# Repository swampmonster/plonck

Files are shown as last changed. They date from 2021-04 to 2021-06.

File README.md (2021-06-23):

# plonck

An attempt at making a planck-compatible pcb with bluetooth  
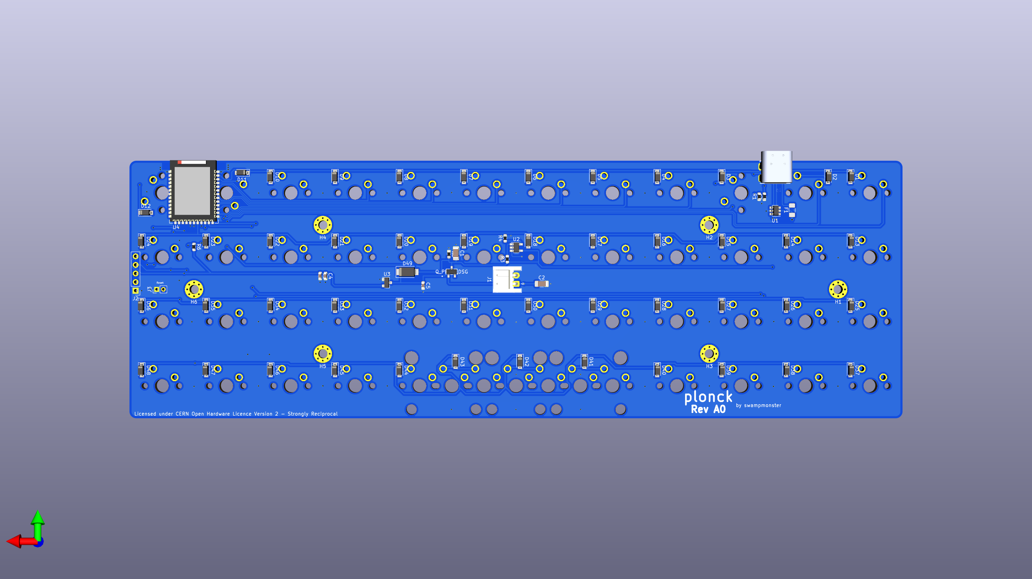
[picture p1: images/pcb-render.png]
PCB Render


## Current status:
### Rev A0 (NOT RECOMMENDED FOR PRODUCTION, READ STATUS)
I've received and built this version and it works fine but i made the mistake of wiring up the GND and VBUS pins on the ESD chip incorrectly.  
Thankfully those are the middle pins and simply desoldering and turning the chip around solves the problem.  
Update: Finally had time to test the load sharing circuitry and i had the pinout of the mosfet setup incorrectly which requires bodge wires to fix.  
If you are looking to get boards made from this revision you need to be aware of this but my recommendation would be to wait for the next one.

## Rev B0
This should address all the issues in A0 while also adding some features that were not previously present such as:  
- Leds for charge and bootloader status.
- Voltage divider for charge monitoring.
- SMD USB port so it can be mounted by JLC.

Boards have been ordered but not yet received so production is still not recommended.

## License
The project is licensed under [CERN-OHL-S](LICENSE) (see [LICENSE](LICENSE) file) with the exceptions of:
- The [MX_Alps_Hybrid](MX_Alps_Hybrid) directory which is licensed under the [MIT License](https://opensource.org/licenses/MIT) and is made by [ai03](https://github.com/ai03-2725/MX_Alps_Hybrid).
- The [USB4085-GF-A_REVA](USB4085-GF-A_REVA) directory which is licensed under the [Creative Commons Attribution-ShareAlike 4.0 International License](https://creativecommons.org/licenses/by-sa/4.0/) and comes from [SnapEDA](https://www.snapeda.com/parts/USB4085-GF-A/Global%20Connector%20Technology/view-part/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).
- The [PTS525SM15SMTR2LFS](PTS525SM15SMTR2LFS) directory which is licensed under the [Creative Commons Attribution-ShareAlike 4.0 International License](https://creativecommons.org/licenses/by-sa/4.0/) and comes from [SnapEDA](https://www.snapeda.com/parts/PTS525SM15SMTR2%20LFS/C&K/view-part/?ref=search&t=PTS525).
- The [SM02B-SRSS-TB_LF__SN_](SM02B-SRSS-TB_LF__SN_) directory which is licensed under the [Creative Commons Attribution-ShareAlike 4.0 International License](https://creativecommons.org/licenses/by-sa/4.0/) and comes from [SnapEDA](https://www.snapeda.com/parts/SM02B-SRSS-TB%28LF%29%28SN%29/JST%20Sales/view-part/447499).
- The [ul_SI2301CDST1GE3](ul_SI2301CDST1GE3) directory which is licensed under the terms provided in the Terms and Conditions on [Ultra Librarian](https://www.ultralibrarian.com/)

## Thanks
Huge shoutout to [4pplet](https://github.com/4pplet) for tons of advice and help.

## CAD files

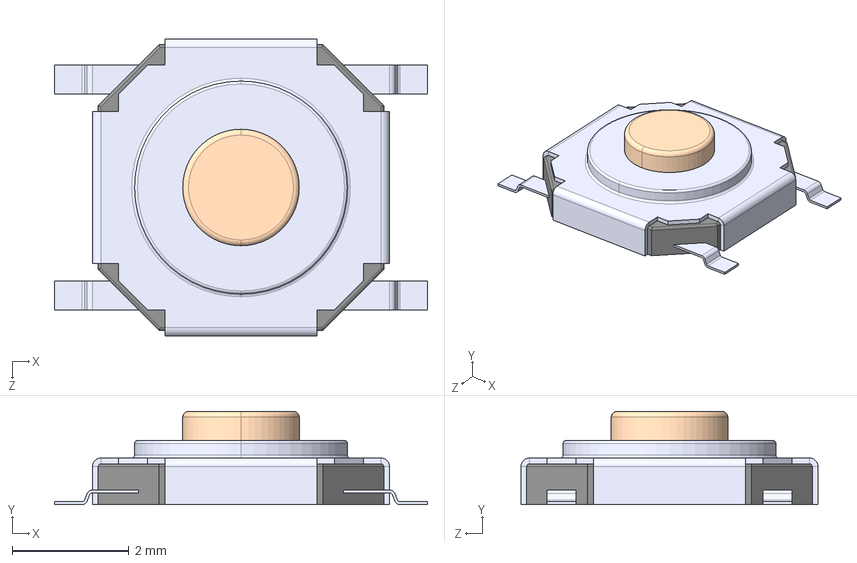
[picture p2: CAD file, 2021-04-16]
PTS525SM15SMTR2LFS/PTS525SM15SMTR2LFS.step
6.40 x 1.60 x 5.10 mm

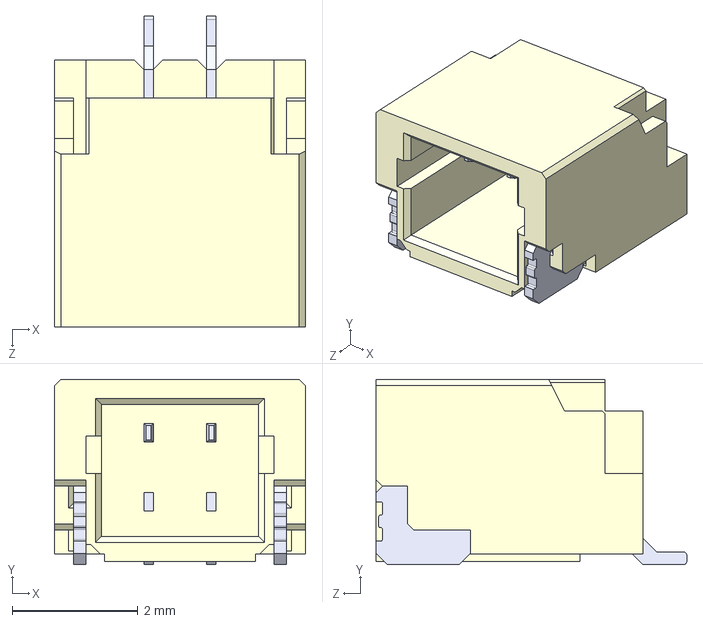
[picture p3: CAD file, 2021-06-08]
SM02B-SRSS-TB_LF__SN_/SM02B-SRSS-TB_LF__SN_.step
4.00 x 2.95 x 4.95 mm

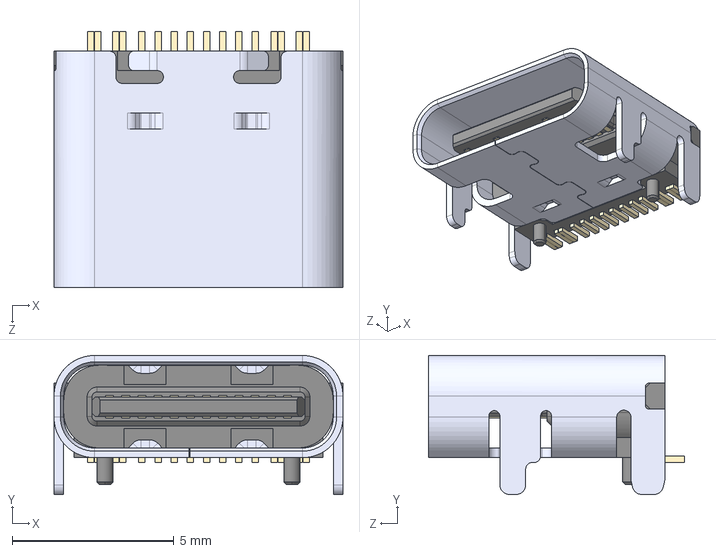
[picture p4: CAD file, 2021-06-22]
TYPE-C-31-M-12--3DModel-STEP-56544.STEP
8.94 x 4.30 x 7.90 mm

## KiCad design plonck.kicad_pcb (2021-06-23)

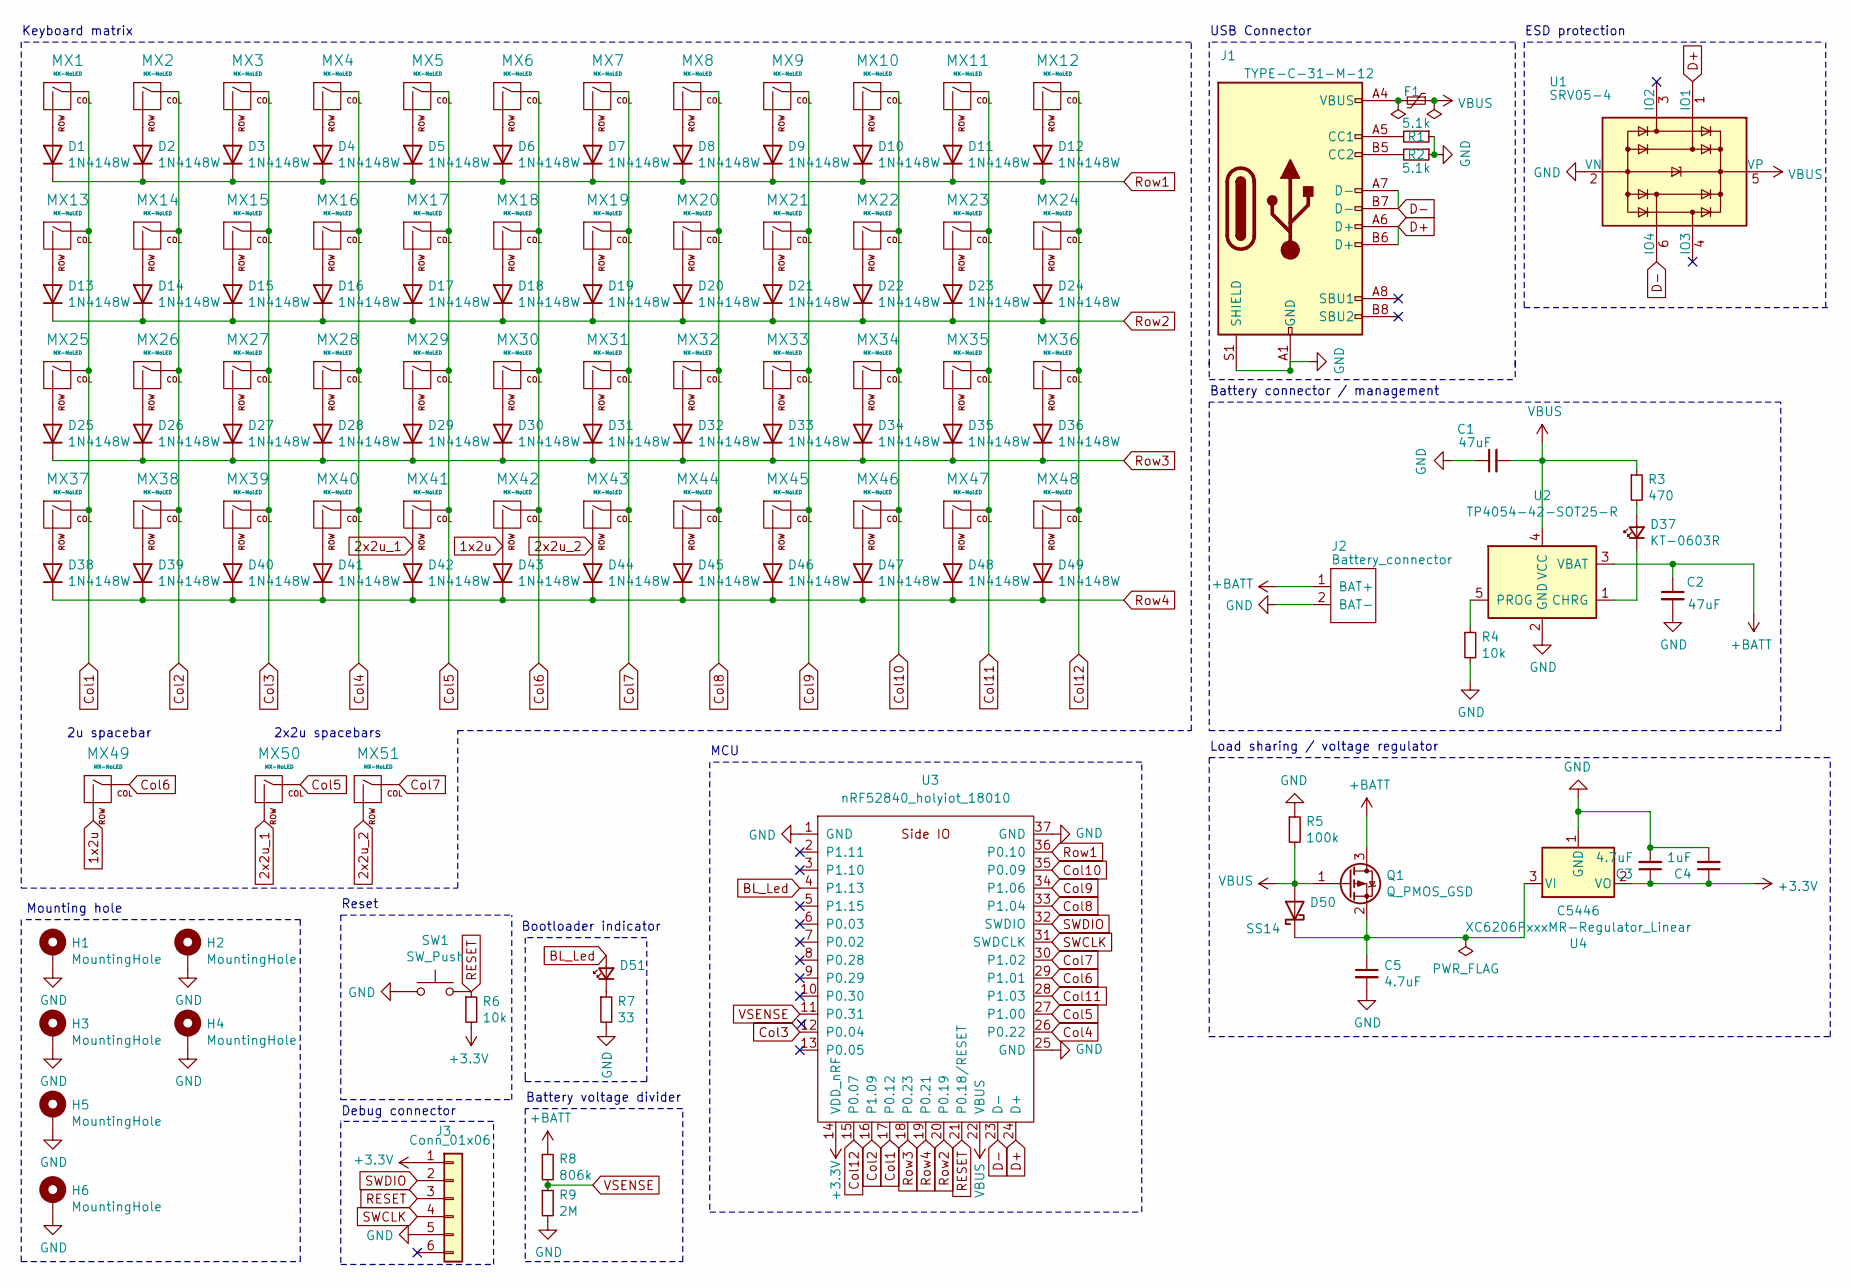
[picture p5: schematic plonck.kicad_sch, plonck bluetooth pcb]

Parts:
C1, C2: 47uF; C_1206_3216Metric; LCSC C96123
C3, C5: 4.7uF; C_0603_1608Metric; LCSC C19666
C4: 1uF; C_0603_1608Metric; LCSC C15849
D1, D2, D3, D4, D5, D6, D7, D8, D9, D10, D11, D12, D13, D14, D15, D16, D17, D18, D19, D20, D21, D22, D23, D24, D25, D26, D27, D28, D29, D30, D31, D32, D33, D34, D35, D36, D38, D39, D40, D41, D42, D43, D44, D45, D46, D47, D48, D49: 1N4148W; D_SOD-123; LCSC C402213
D37: KT-0603R; LED_0603_1608Metric; LCSC C2286
D50: SS14; D_SMA; LCSC C2480
D51: 19-217/BHC-ZL1M2RY/3T; LED_0603_1608Metric; LCSC C72041
F1: SMD Fuse Fast Blow 500mA; Fuse_1206_3216Metric; LCSC C182974
H1, H2, H3, H4, H5, H6: MountingHole; MountingHole_2.7mm_M2.5_Pad_TopBottom
J1: TYPE-C-31-M-12; USB_C_Receptacle_HRO_TYPE-C-31-M-12; LCSC C165948
J2: Battery_connector; SM02B-SRSS-TB(LF)(SN)
J3: Conn_01x06; Tag-Connect_TC2030-IDC-NL_2x03_P1.27mm_Vertical
MX1, MX2, MX3, MX4, MX5, MX6, MX7, MX8, MX9, MX10, MX11, MX12, MX13, MX14, MX15, MX16, MX17, MX18, MX19, MX20, MX21, MX22, MX23, MX24, MX25, MX26, MX27, MX28, MX29, MX30, MX31, MX32, MX33, MX34, MX35, MX36, MX37, MX38, MX39, MX40, MX41, MX42, MX43, MX44, MX45, MX46, MX47, MX48: MX-NoLED; MX-1U-NoLED
MX49, MX50, MX51: MX-NoLED; MX-2U-ReversedStabilizers-NoLED
Q1: Q_PMOS_GSD; SI2301CDS-T1-GE3; LCSC C10487
R1, R2: 5.1k; R_0603_1608Metric; Digikey RMCF0603JT5K10TR-ND
R3: 470; R_0603_1608Metric; Digikey RMCF0603JT470RTR-ND
R4, R6: 10k; R_0603_1608Metric; LCSC C25804
R5: 100k; R_0603_1608Metric; Digikey RMCF0603JG100KTR-ND
R7: 33; R_0603_1608Metric; LCSC C23140
R8: 806k; R_0603_1608Metric; LCSC C23250
R9: 2M; R_0603_1608Metric; LCSC C22976
SW1: SW_Push; SW_Push_SPST_NO_Alps_SKRK; LCSC C115357
U1: SRV05-4; SOT-23-6; LCSC C782797
U2: TP4054-42-SOT25-R; TSOT-23-5; LCSC C32574
U3: nRF52840_holyiot_18010; nRF52840_holyiot_18010_HS_simple
U4: XC6206PxxxMR-Regulator_Linear; SOT-23; LCSC C5446

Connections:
1x2u: D43.2 (A), MX42.2 (ROW), MX49.2 (ROW)
2x2u_1: D42.2 (A), MX41.2 (ROW), MX50.2 (ROW)
2x2u_2: D44.2 (A), MX43.2 (ROW), MX51.2 (ROW)
+3V3: C3.1, C4.1, J3.1, R6.2, U3.14 (VDD_nRF), U4.2 (VO)
+BATT: C2.1, J2.1 (BAT+), Q1.3 (D), R8.1, U2.3 (VBAT)
BL_Led: D51.2 (A), U3.4 (P1.13)
Col1: MX1.1 (COL), MX13.1 (COL), MX25.1 (COL), MX37.1 (COL), U3.17 (P0.12)
Col2: MX2.1 (COL), MX14.1 (COL), MX26.1 (COL), MX38.1 (COL), U3.16 (P1.09)
Col3: MX3.1 (COL), MX15.1 (COL), MX27.1 (COL), MX39.1 (COL), U3.12 (P0.04)
Col4: MX4.1 (COL), MX16.1 (COL), MX28.1 (COL), MX40.1 (COL), U3.26 (P0.22)
Col5: MX5.1 (COL), MX17.1 (COL), MX29.1 (COL), MX41.1 (COL), MX50.1 (COL), U3.27 (P1.00)
Col6: MX6.1 (COL), MX18.1 (COL), MX30.1 (COL), MX42.1 (COL), MX49.1 (COL), U3.29 (P1.01)
Col7: MX7.1 (COL), MX19.1 (COL), MX31.1 (COL), MX43.1 (COL), MX51.1 (COL), U3.30 (P1.02)
Col8: MX8.1 (COL), MX20.1 (COL), MX32.1 (COL), MX44.1 (COL), U3.33 (P1.04)
Col9: MX9.1 (COL), MX21.1 (COL), MX33.1 (COL), MX45.1 (COL), U3.34 (P1.06)
Col10: MX10.1 (COL), MX22.1 (COL), MX34.1 (COL), MX46.1 (COL), U3.35 (P0.09)
Col11: MX11.1 (COL), MX23.1 (COL), MX35.1 (COL), MX47.1 (COL), U3.28 (P1.03)
Col12: MX12.1 (COL), MX24.1 (COL), MX36.1 (COL), MX48.1 (COL), U3.15 (P0.07)
D+: J1.A6 (D+), J1.B6 (D+), U1.1 (IO1), U3.24 (D+)
D-: J1.A7 (D-), J1.B7 (D-), U1.6 (IO4), U3.23 (D-)
GND: C1.1, C2.2, C3.2, C4.2, C5.2, H1.1, H2.1, H3.1, H4.1, H5.1, H6.1, J1.A1 (GND), J1.A12 (GND), J1.B1 (GND), J1.B12 (GND), J1.S1 (SHIELD), J2.2 (BAT-), J2.3, J2.4, J3.5, R1.1, R2.1, R4.2, R5.1, R7.2, R9.2, SW1.1, U1.2 (VN), U2.2 (GND), U3.1 (GND), U3.25 (GND), U3.37 (GND), U4.1 (GND)
unnamed: C5.1, D50.1, Q1.2 (S), U4.3 (VI)
unnamed: D1.2 (A), MX1.2 (ROW)
unnamed: D2.2 (A), MX2.2 (ROW)
unnamed: D3.2 (A), MX3.2 (ROW)
unnamed: D4.2 (A), MX4.2 (ROW)
unnamed: D5.2 (A), MX5.2 (ROW)
unnamed: D6.2 (A), MX6.2 (ROW)
unnamed: D7.2 (A), MX7.2 (ROW)
unnamed: D8.2 (A), MX8.2 (ROW)
unnamed: D9.2 (A), MX9.2 (ROW)
unnamed: D10.2 (A), MX10.2 (ROW)
unnamed: D11.2 (A), MX11.2 (ROW)
unnamed: D12.2 (A), MX12.2 (ROW)
unnamed: D13.2 (A), MX13.2 (ROW)
unnamed: D14.2 (A), MX14.2 (ROW)
unnamed: D15.2 (A), MX15.2 (ROW)
unnamed: D16.2 (A), MX16.2 (ROW)
unnamed: D17.2 (A), MX17.2 (ROW)
unnamed: D18.2 (A), MX18.2 (ROW)
unnamed: D19.2 (A), MX19.2 (ROW)
unnamed: D20.2 (A), MX20.2 (ROW)
unnamed: D21.2 (A), MX21.2 (ROW)
unnamed: D22.2 (A), MX22.2 (ROW)
unnamed: D23.2 (A), MX23.2 (ROW)
unnamed: D24.2 (A), MX24.2 (ROW)
unnamed: D25.2 (A), MX25.2 (ROW)
unnamed: D26.2 (A), MX26.2 (ROW)
unnamed: D27.2 (A), MX27.2 (ROW)
unnamed: D28.2 (A), MX28.2 (ROW)
unnamed: D29.2 (A), MX29.2 (ROW)
unnamed: D30.2 (A), MX30.2 (ROW)
unnamed: D31.2 (A), MX31.2 (ROW)
unnamed: D32.2 (A), MX32.2 (ROW)
unnamed: D33.2 (A), MX33.2 (ROW)
unnamed: D34.2 (A), MX34.2 (ROW)
unnamed: D35.2 (A), MX35.2 (ROW)
unnamed: D36.2 (A), MX36.2 (ROW)
unnamed: D37.1 (K), U2.1 (CHRG)
unnamed: D37.2 (A), R3.2
unnamed: D38.2 (A), MX37.2 (ROW)
unnamed: D39.2 (A), MX38.2 (ROW)
unnamed: D40.2 (A), MX39.2 (ROW)
unnamed: D41.2 (A), MX40.2 (ROW)
unnamed: D45.2 (A), MX44.2 (ROW)
unnamed: D46.2 (A), MX45.2 (ROW)
unnamed: D47.2 (A), MX46.2 (ROW)
unnamed: D48.2 (A), MX47.2 (ROW)
unnamed: D49.2 (A), MX48.2 (ROW)
unnamed: D51.1 (K), R7.1
unnamed: F1.2, J1.A4 (VBUS), J1.A9 (VBUS), J1.B4 (VBUS), J1.B9 (VBUS)
unnamed: J1.A5 (CC1), R1.2
unnamed: J1.B5 (CC2), R2.2
unnamed: R4.1, U2.5 (PROG)
RESET: J3.3, R6.1, SW1.2, U3.21 (P0.18/RESET)
Row1: D1.1 (K), D2.1 (K), D3.1 (K), D4.1 (K), D5.1 (K), D6.1 (K), D7.1 (K), D8.1 (K), D9.1 (K), D10.1 (K), D11.1 (K), D12.1 (K), U3.36 (P0.10)
Row2: D13.1 (K), D14.1 (K), D15.1 (K), D16.1 (K), D17.1 (K), D18.1 (K), D19.1 (K), D20.1 (K), D21.1 (K), D22.1 (K), D23.1 (K), D24.1 (K), U3.20 (P0.19)
Row3: D25.1 (K), D26.1 (K), D27.1 (K), D28.1 (K), D29.1 (K), D30.1 (K), D31.1 (K), D32.1 (K), D33.1 (K), D34.1 (K), D35.1 (K), D36.1 (K), U3.18 (P0.23)
Row4: D38.1 (K), D39.1 (K), D40.1 (K), D41.1 (K), D42.1 (K), D43.1 (K), D44.1 (K), D45.1 (K), D46.1 (K), D47.1 (K), D48.1 (K), D49.1 (K), U3.19 (P0.21)
SWCLK: J3.4, U3.31 (SWDCLK)
SWDIO: J3.2, U3.32 (SWDIO)
VBUS: C1.2, D50.2, F1.1, Q1.1 (G), R3.1, R5.2, U1.5 (VP), U2.4 (VCC), U3.22 (VBUS)
VSENSE: R8.2, R9.1, U3.11 (P0.31)

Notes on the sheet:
Keyboard matrix
Mounting hole
2u spacebar
2x2u spacebars
Reset
Debug connector
Bootloader indicator
Battery voltage divider
MCU
USB Connector
Battery connector / management
Load sharing / voltage regulator
ESD protection

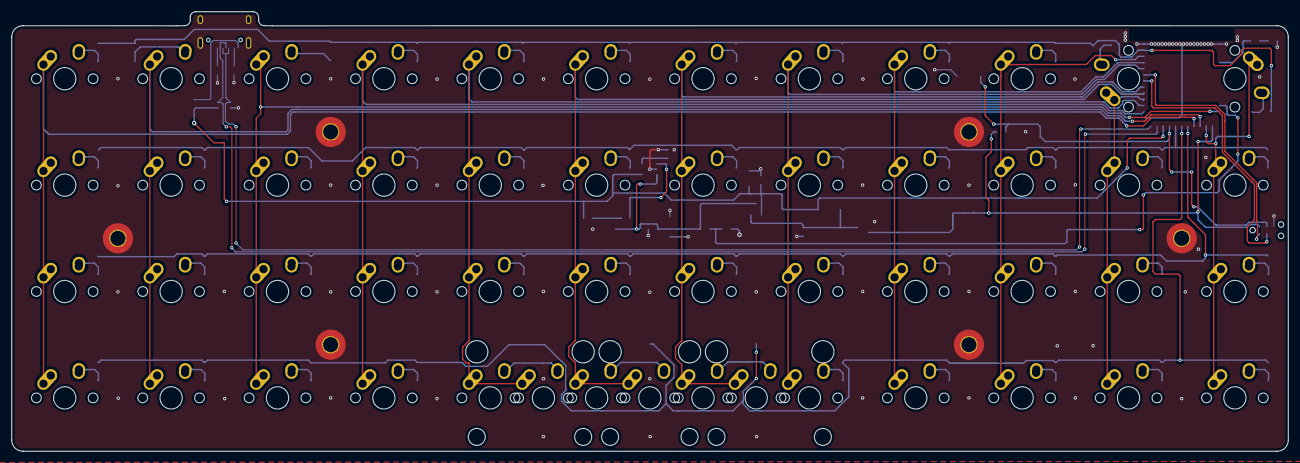
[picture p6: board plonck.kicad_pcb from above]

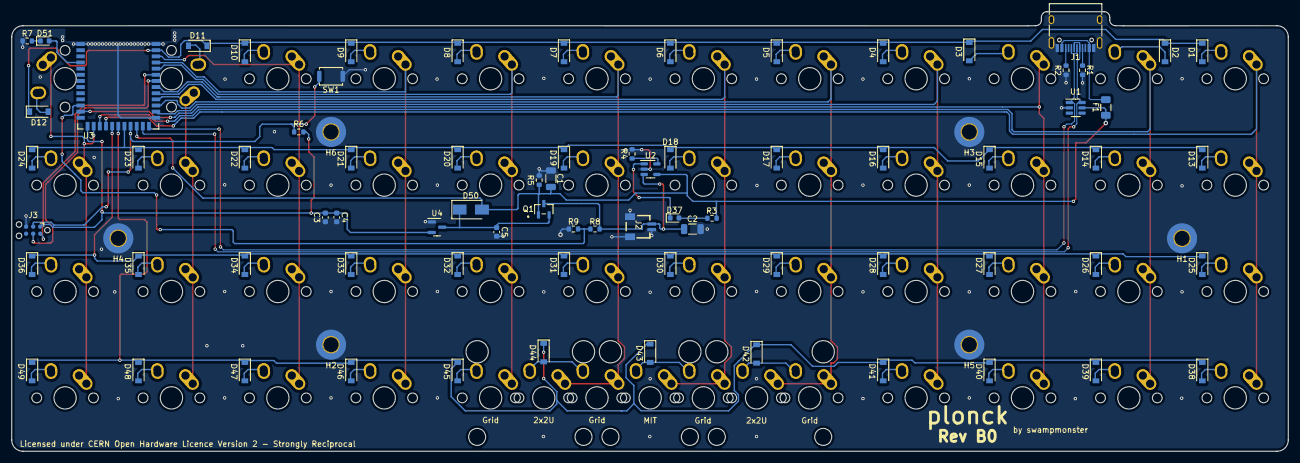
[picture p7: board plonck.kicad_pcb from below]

Board: 2 copper layers, 228.6 x 78.7 mm, 132 parts (81 on the bottom side), 83 nets.

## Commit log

2021-04-19 updated some fooprints and added lcsc part numbers
    [plonck.kicad_pcb, plonck.sch]
2021-04-20 added ground fill on top layer
    [plonck.kicad_pcb]
2021-04-20 updated parts and fixed ground fill
    [plonck.kicad_pcb, plonck.sch]
2021-04-22 fixing up via sizes and ground planes
    [plonck.kicad_pcb, plonck.sch]
2021-04-22 added missing lcsc part number
    [plonck.kicad_pcb, plonck.sch]
2021-04-24 bunch of fixes and changes to use only basic parts from lcsc
    [plonck.kicad_pcb, plonck.sch]
2021-04-26 updated board render
2021-05-14 rescue stuff
    [plonck.kicad_pcb, plonck.sch]
2021-05-23 various fixes and additions
    changed switch footprints to be alps compatible
    added descriptive text to bottom row
    fixed mounting holes not being connected to ground
    fixed incorrectly wired esd chip
    added reset switch in default planck position
    changed mx3 to normal rotation
    changed board outline to move usb port further out
    [plonck.kicad_pcb, plonck.sch]
2021-06-01 fixed incorrect schematic symbol for mosfet
    [plonck.kicad_pcb, plonck.sch]
2021-06-01 added charge status led
    [plonck.kicad_pcb, plonck.sch]
2021-06-01 added vsense circuitry
    [plonck.kicad_pcb, plonck.sch]
2021-06-02 updated resistor values in battery voltage divider
    [plonck.kicad_pcb, plonck.sch]
2021-06-03 added bootloader status led
    [plonck.kicad_pcb, plonck.sch]
2021-06-07 updated resistor values for vsense
    https://devzone.nordicsemi.com/nordic/nordic-blog/b/blog/posts/measuring-lithium-battery-voltage-with-nrf52
    [plonck.kicad_pcb, plonck.sch]
2021-06-08 added symbols for battery connector
    [SM02B-SRSS-TB_LF__SN_.step]
2021-06-08 changed battery connector to smaller size
    [plonck.kicad_pcb, plonck.sch]
2021-06-20 updating ignores for new version of kicad
2021-06-20 bunch of updates and fixes related to new kicad version
    [plonck.kicad_pcb, plonck.kicad_sch]
2021-06-20 more fixing
    [plonck.kicad_pcb, plonck.kicad_sch]
2021-06-20 added holyiot module footprint
2021-06-20 updated board revision
    [plonck.kicad_pcb, plonck.kicad_sch]
2021-06-20 more more fixing
    [plonck.kicad_pcb, plonck.kicad_sch]
2021-06-22 various updates
    * switched to smd usb-c port
    * updated various lcsc part numbers
    [TYPE-C-31-M-12--3DModel-STEP-56544.STEP, plonck.kicad_pcb, plonck.kicad_sch]
2021-06-23 adding/fixing lcsc part numbers
    [plonck.kicad_pcb, plonck.kicad_sch]

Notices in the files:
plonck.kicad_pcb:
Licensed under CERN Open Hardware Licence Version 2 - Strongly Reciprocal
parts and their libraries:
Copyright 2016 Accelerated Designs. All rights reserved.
